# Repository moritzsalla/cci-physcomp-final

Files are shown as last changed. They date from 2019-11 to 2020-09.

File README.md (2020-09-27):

# Theremin

Experiemental instrument that uses light as an interface to output tones & melodies. It can be played by a single player or as a dialog between two.

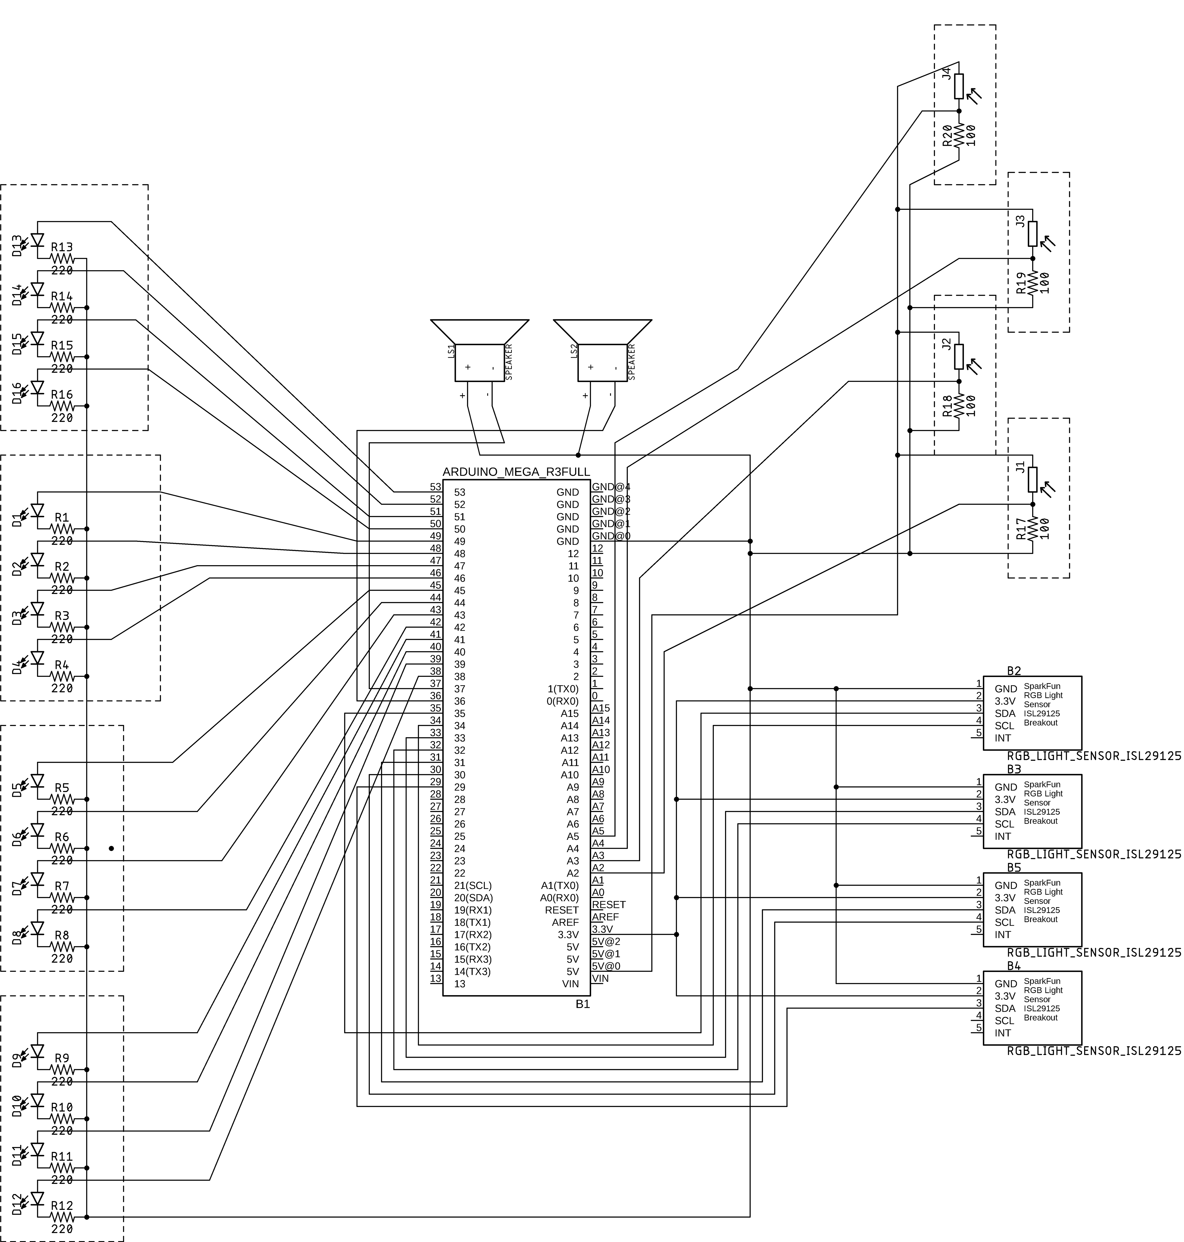
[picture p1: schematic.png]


## Dependencies

1. SoftWire
2. ISL29125 SoftWire

## Folder Structure

```
.
├── README.md
├── code
│   ├── libs
│   │   ├── ISL29125_softwire
│   │   │   ├── LICENSE.md
│   │   │   ├── README.md
│   │   │   ├── examples
│   │   │   │   └── ISL29125Basics
│   │   │   │       └── ISL29125Basics.ino
│   │   │   ├── library.properties
│   │   │   └── src
│   │   │       ├── ISL29125_SoftWire.cpp
│   │   │       └── ISL29125_SoftWire.h
│   │   └── softwire
│   │       ├── README.TXT
│   │       ├── SoftwareWire.cpp
│   │       ├── SoftwareWire.h
│   │       ├── examples
│   │       │   ├── Small_example
│   │       │   │   └── Small_example.ino
│   │       │   ├── StressTest_Master
│   │       │   │   └── StressTest_Master.ino
│   │       │   └── StressTest_Slave
│   │       │       └── StressTest_Slave.ino
│   │       ├── keywords.txt
│   │       └── library.properties
│   └── theremin
│       ├── calibration.ino
│       ├── header.h
│       ├── light.ino
│       ├── read.ino
│       ├── theremin.ino
│       └── tone.ino
├── journal
│   ├── log-01
│   │   ├── README.md
│   │   ├── render-1.jpg
│   │   ├── render-2.jpg
│   │   ├── scan-001.png
│   │   ├── scan-002.png
│   │   ├── scan-003.png
│   │   ├── scan-004.png
│   │   ├── scan-005.png
│   │   ├── scan-006.png
│   │   ├── scan-007.png
│   │   ├── scan-008.png
│   │   ├── scan-009.png
│   │   ├── scan-010.png
│   │   ├── scan-011.png
│   │   ├── scan-012.png
│   │   └── scan-013.png
│   ├── log-02
│   │   ├── README.md
│   │   ├── image-001.jpeg
│   │   ├── image-002.jpeg
│   │   ├── image-003.jpeg
│   │   ├── image-004.jpeg
│   │   ├── image-005.jpeg
│   │   ├── image-006.jpeg
│   │   ├── image-007.jpeg
│   │   └── image-008.jpeg
│   ├── log-03
│   │   ├── README.md
│   │   ├── image-1.jpg
│   │   ├── image-2.jpg
│   │   ├── image-3.jpg
│   │   ├── image-4.jpg
│   │   ├── image-5.jpeg
│   │   ├── schematic.jpg
│   │   ├── screenshot-1.png
│   │   ├── screenshot-2.png
│   │   └── screenshot-3.png
│   ├── log-04
│   │   ├── Bildschirmfoto\ 2019-11-26\ um\ 15.17.12.png
│   │   ├── Bildschirmfoto\ 2019-12-06\ um\ 18.15.19.png
│   │   ├── Bildschirmfoto\ 2019-12-06\ um\ 18.15.39.png
│   │   ├── README.md
│   │   ├── image-1.jpg
│   │   ├── image-2.jpg
│   │   ├── image-3.jpg
│   │   ├── screenshot-0.png
│   │   ├── screenshot-1.png
│   │   └── screenshot-2.png
│   ├── log-05
│   │   ├── README.md
│   │   ├── image-01.jpeg
│   │   ├── image-02.jpeg
│   │   ├── image-03.jpeg
│   │   ├── image-04.jpeg
│   │   ├── image-05.jpeg
│   │   ├── image-06.jpeg
│   │   ├── image-07.jpeg
│   │   ├── image-08.jpeg
│   │   ├── image-09.jpeg
│   │   ├── image-10.jpeg
│   │   ├── image-11.jpeg
│   │   └── image-12.jpeg
│   ├── log-06
│   │   ├── README.md
│   │   └── render.jpg
│   ├── log-07
│   │   ├── README.md
│   │   └── image-1.png
│   ├── log-08
│   │   ├── README.md
│   │   ├── image-1.jpeg
│   │   ├── image-2.jpeg
│   │   ├── image-3.jpeg
│   │   ├── image-4.jpeg
│   │   └── image.png
│   ├── log-09
│   │   ├── README.md
│   │   └── schematic.png
│   └── log-10
│       ├── README.md
│       ├── image-1.jpg
│       └── schematic.png
├── presentations
│   ├── final.pdf
│   ├── proposal.pdf
│   └── theremin-1.mp4
├── renderings
│   ├── render-1.jpg
│   ├── render-2.jpg
│   ├── render-3.jpg
│   └── render.gif
└── schematic.png
```

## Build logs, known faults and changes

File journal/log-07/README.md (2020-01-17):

# Log 7

### Using millisec instead of delay

Fading my led torches is all fun and games until you want to do something in parallel. The delay function will block your loop. The solution to this is to use milliseconds.

### Fading the LED torches

Another solution had to be found, and hence I settled on a function that would allow me to use time and a sine wave to fade the LEDs. Not only does this solve the timing problem, the sine wave fade is much better looking than the linear for loop fade.

https://youtu.be/ubPF3j_LVvM

https://youtu.be/BusSimIUbJU

```c++
int LEDval, LEDval2;

void light () {
      LEDval = 128 + 128 * sin(2 * PI / frequency * (millis()));
      analogWrite(ledA1, LEDval);
}
```

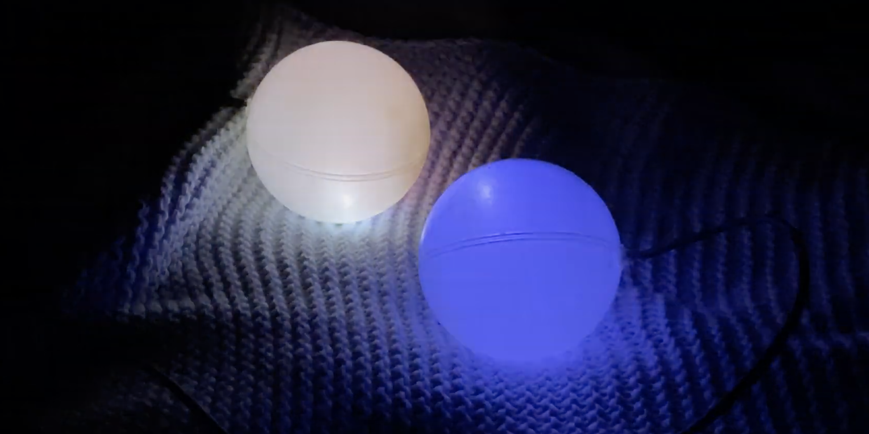
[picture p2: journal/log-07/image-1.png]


In order to have the two run asynchonously, one has to run on an offset. This can be easily achieved by using a sine curve on one, and a cosine curve on another value.

```c++
LEDval = 128 + 128 * sin(2 * PI / frequency * (millis()));

LEDval2 = 128 + 128 * cos(2 * PI / frequency * (millis()));
```

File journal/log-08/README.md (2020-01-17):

# Log 8

#### Complex tones

This by far became the most challengin aspect of my porject. By standard, the tone function is limited to a single output. Also, the square wave that the Arduino produces sounds harsh on the ears. Creating something that would be more complex than a simple one to one reading of the sensor values wasn't going to be easy.

Tryout using random() to create tones—not quite what I am going for:

https://youtu.be/zJvzaO4Gy4U

The low accuracy of the RGB sensors returns this magnificent staggered wave. It's much easier on the ear than a continuous tone, and sounds remarkeably interesting.

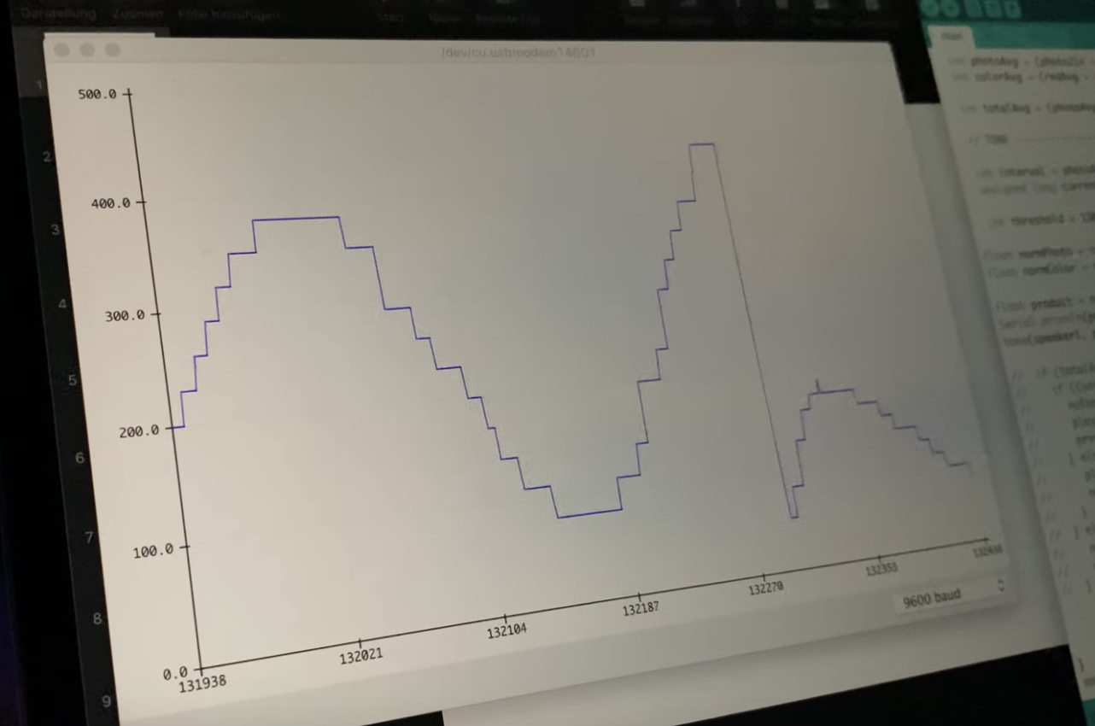
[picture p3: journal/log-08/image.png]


https://youtu.be/a39MprkitpA

When the frequency drops below a certain value, the loudspeakers will start to play random pitches until the value of zero. Don't quite understand why this is happening. I have mapped the value so that these frequencies are omitted.

#### Finding a better material for the enclosure

Went to another art supply shop. Silicone/latex seems the way to go. He only had the brown one though, albeit selling pigments. Pigments wont work because they likely make the material opaque. I need it semi translucent. Need to order this stuff on the internet. I ended up using a mixture of latex thickener and white color to create the desired effect.

The LED torches were a challenge to coat. I initially wanted to create a surface that would monotonously disperse light just like the Playstation controllers. I quickly discovered that the tactility of latex adds a lot to my project. The plastic baubles were suddenly satisfying to grip, didn't slip and looked more approachable. Latex became a signifier, I guess?

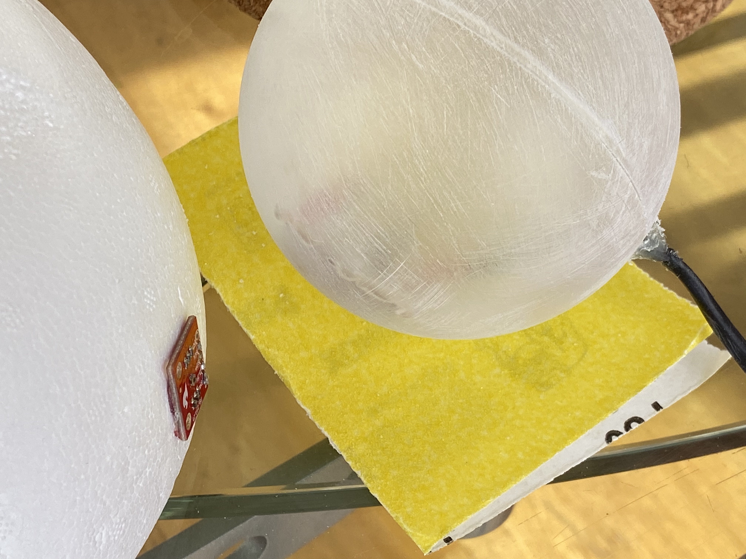
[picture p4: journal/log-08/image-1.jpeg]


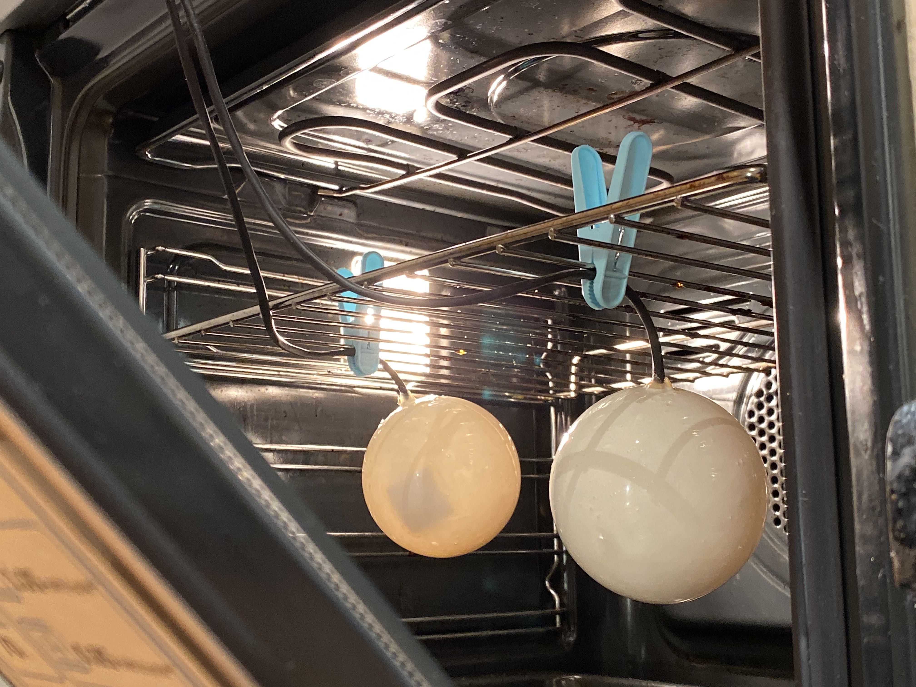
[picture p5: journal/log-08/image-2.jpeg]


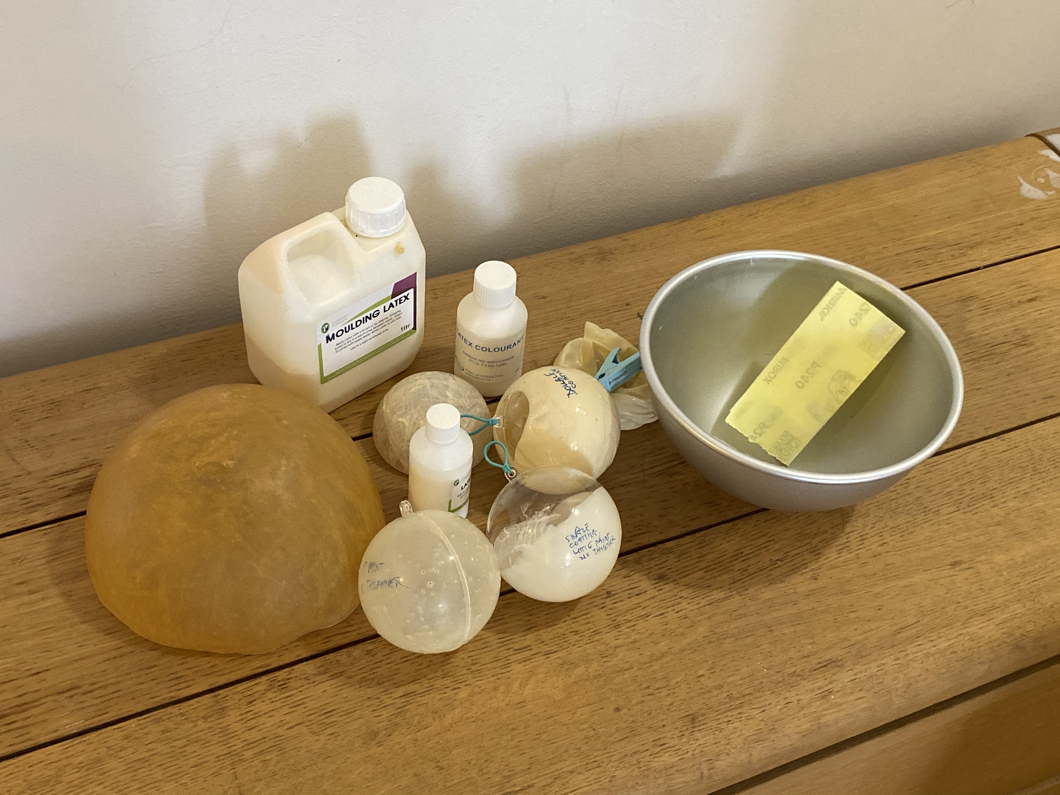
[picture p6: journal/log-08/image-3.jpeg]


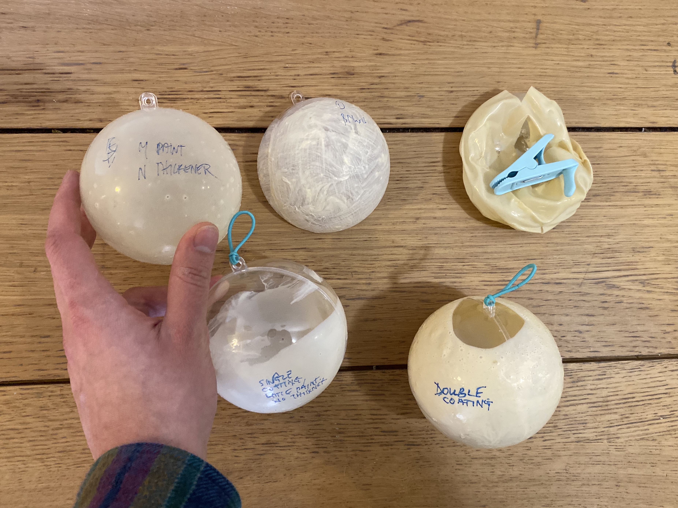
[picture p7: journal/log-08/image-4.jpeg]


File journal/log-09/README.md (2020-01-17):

# Log 9

## Redoing the circuit diagram

I figured that the fritzing diagram I made was not actually a schematic. Since I had to redo this, I took the challenge to make it in Eagle, the program with one of the scariest interfaces I have ever seen (or lack thereof). Getting all of my sensors onto a single diagram proved to be quite difficult, as I quickly ran out of space for my nets.

Schematic

## Distance sensor

In order to create a threshold in which the instrument turns on, I used the photoresistor readings. If the value goes above a cetrain amount, a tone will be played, whereas it will be stopped should the value drop. I have basically created a distance sensor from photoresistors.

## Enclosure and sensors work together

Things are coming together now. I was slightly concerned the color sensors wouldn't work properly with the reddish latex enclosure but it works perfectly. Interestingly I can use shadow instead of light, and it will have the inverted effect on my sensors. This is an alternative way of interacting with the instrument, and an ally I could further explore.

https://youtu.be/4mwHbQ01Eho

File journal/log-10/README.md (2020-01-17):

# Log 10

## Naming my instrument

My aunt hinted that what I had created already existed, and was called a **Theremin**. Albeit this being an instrument that works with a single input and a single output, the core concept seemed to be similar to mine: to create music without direct physcial interaction. Therefor, I chose to adapt the name Theremin. Here is a short description of the original instrument, found on Wikipedia:

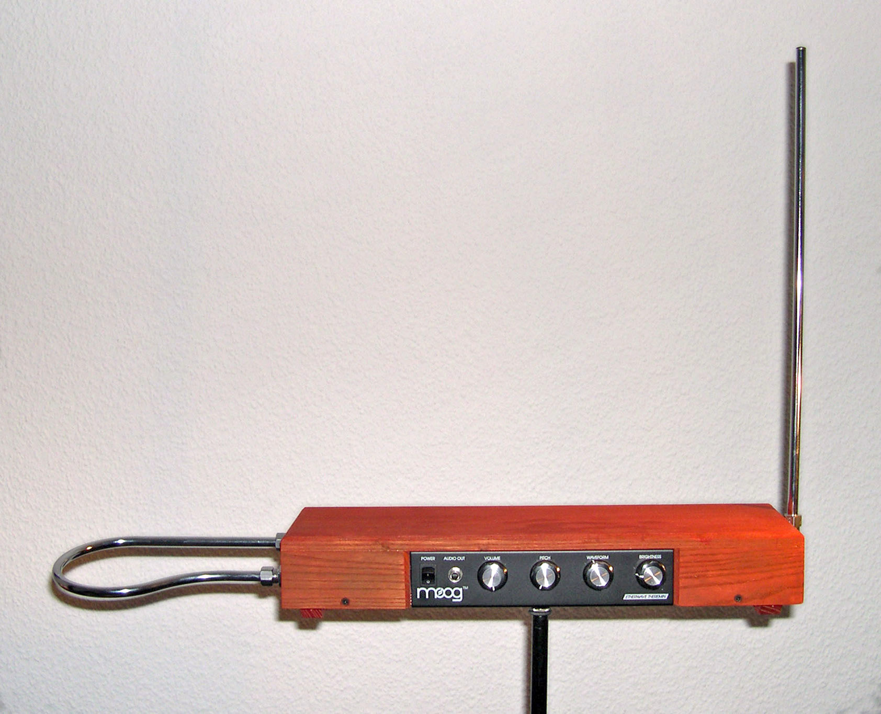
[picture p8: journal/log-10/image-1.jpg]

_Theremin. Image taken from wikipedia._

**_The theremin is an electronic musical instrument controlled without physical contact by the thereminist. It is named after its inventor, Léon Theremin, who patented the device in 1928._**

## Adding a calibration routine

When working with light, calibration is crucial. Light changes constantly—even dark rooms differ in ambient lighting. I could'nt propperly showcase my project in CCi as the building is covered in glass. However, my feedback was to add a calibration routine to my script, in order for Theremin to automatically adjust to ambient light levels. This code represents a single calibration routine, taken from an Arduino tutorial:

```c++
void setup() {
  pinMode(13, OUTPUT);
  digitalWrite(13, HIGH);

  while (millis() < 5000) {
    sensorValue = analogRead(sensorPin);

    if (sensorValue > sensorMax) {
      sensorMax = sensorValue;
    }

    if (sensorValue < sensorMin) {
      sensorMin = sensorValue;
    }
  }
  digitalWrite(13, LOW);
}

void loop() {
  sensorValue = analogRead(sensorPin);

  sensorValue = map(sensorValue, sensorMin, sensorMax, 0, 255);

  sensorValue = constrain(sensorValue, 0, 255);

  analogWrite(ledPin, sensorValue);
}
```

I have done this for the photoresistors. The color sensors actually don't need calibration, because there tends to be very little color in dark rooms. The readings seem very consistent. Perhaps the library that comes with the RGB color sensors includes its own calibration routine. I did look through the code. Can't remember having seen one though. Furthermore, the threshold that determines when the instrument turns on doesn't have to be calibrated either, as the calibrated photoresistor input will yield the same results.

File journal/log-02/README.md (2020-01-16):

# Log 2

I've started ordering components. Four ambient light sensors to be specific. Initially, I wanted to go for more than four sensors of each sort but since spending such an amount of money didn't increase the accuracy much, I cut it down to four.

In the meantime, I started soldering little breakout boards for the photoresistors. Not only will this reduce the cable salad on my central perfboard by compartmentalizing the components, but it'll also be more reliable.

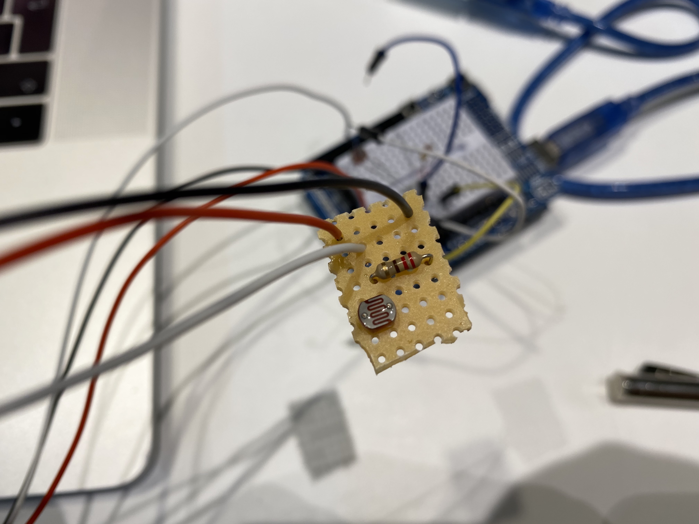
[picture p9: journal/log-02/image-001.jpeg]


Taping the cables together close to the breakout board will helpfully spread force to all of the cables should they be accidentally pulled. This'll hopefully reduce the chance of a cable getting lose. Since I'm dealing with so many sensors at once, it'll be a nightmare to spot errors if things go wrong. Better be safe then sorry.



For now I am using this styrophome ball to prototype. I poke holes into the ball in order to bring all the technology together on the inside. The sensors will be stuck, not floating around like in the picture.

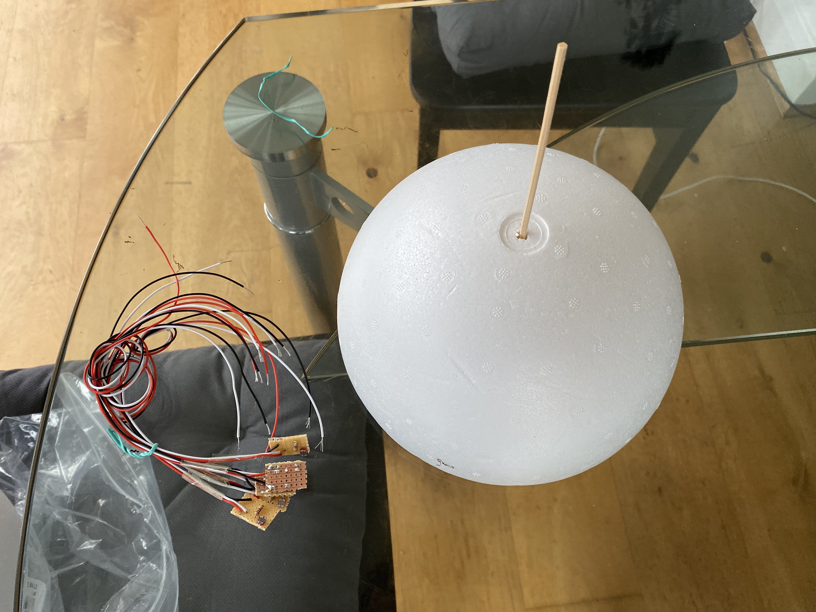
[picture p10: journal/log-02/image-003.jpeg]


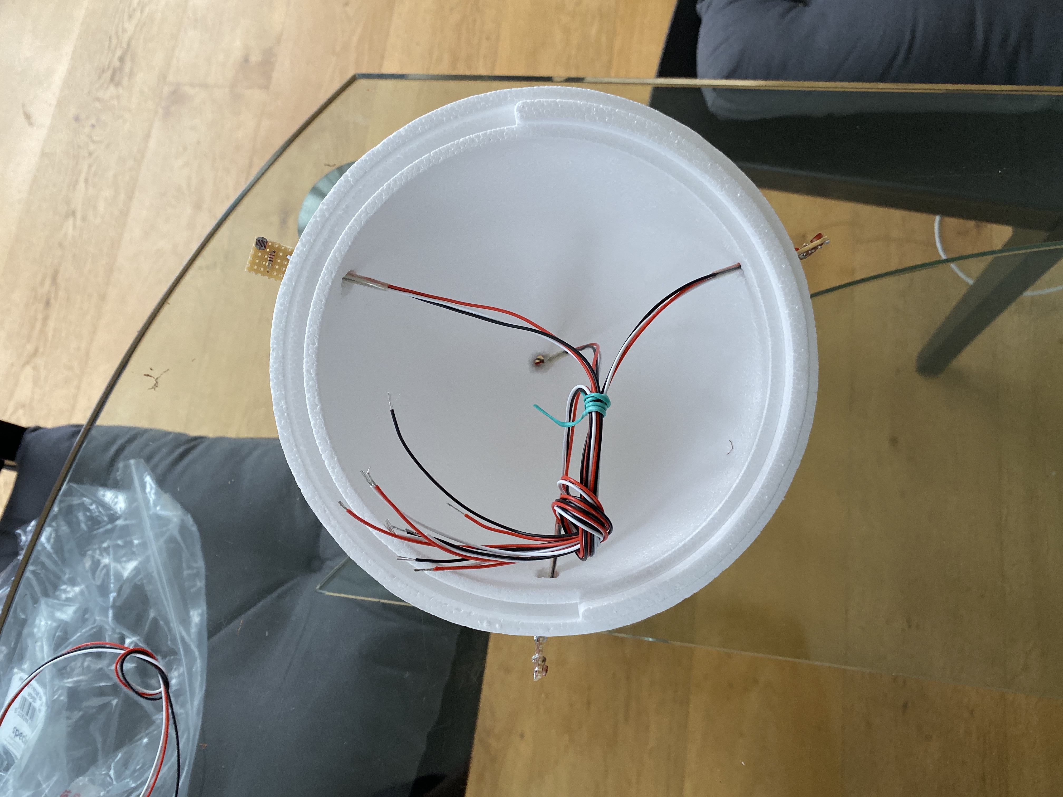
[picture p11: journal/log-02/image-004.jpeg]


The ambient light sensors (ISL29125 RGB Light Sensor [SEN-12829]) have arrived and I am testing them out. They work! The output is in HEX color values—I hope Arduino provides an easy way to convert these to floating-point. One of these breakout boards requires two analog ins. Here is the official documentation: https://learn.sparkfun.com/tutorials/isl29125-rgb-light-sensor-hookup-guide

**Two important points to remember about these sensors:**<br>

1. The chip is not 5V tolerant and will be damaged if you apply 5V to power or any of the inputs
2. Connect the 3.3V and GND on the Arduino to the 3.3V pin on the breakout board. Connect SDA on the breakout to A4 on the Uno, SCL to A5 on the Uno.

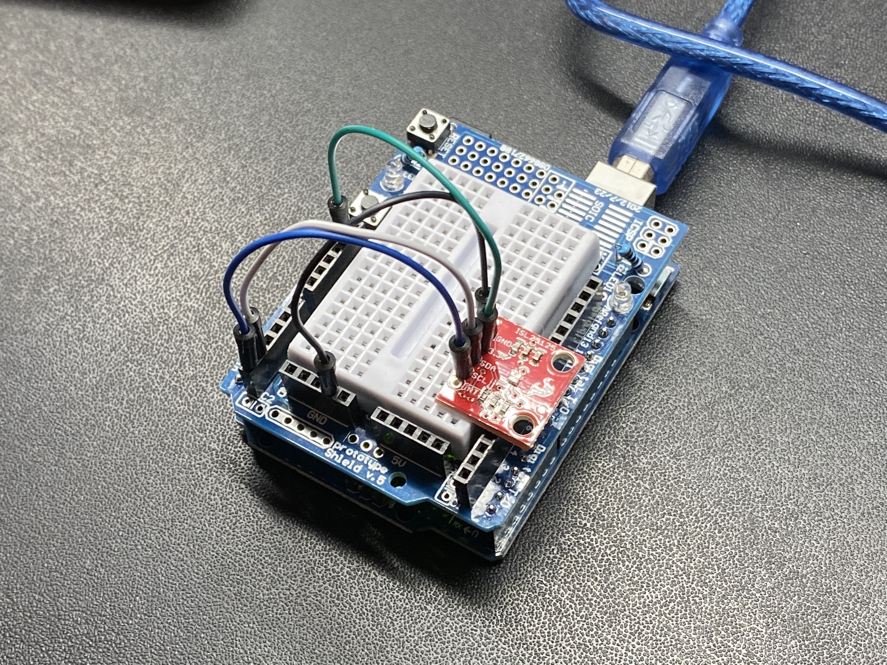
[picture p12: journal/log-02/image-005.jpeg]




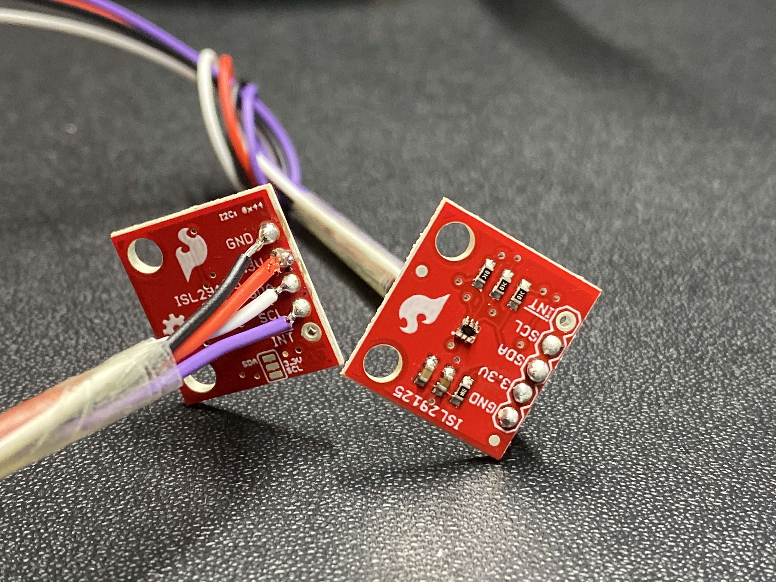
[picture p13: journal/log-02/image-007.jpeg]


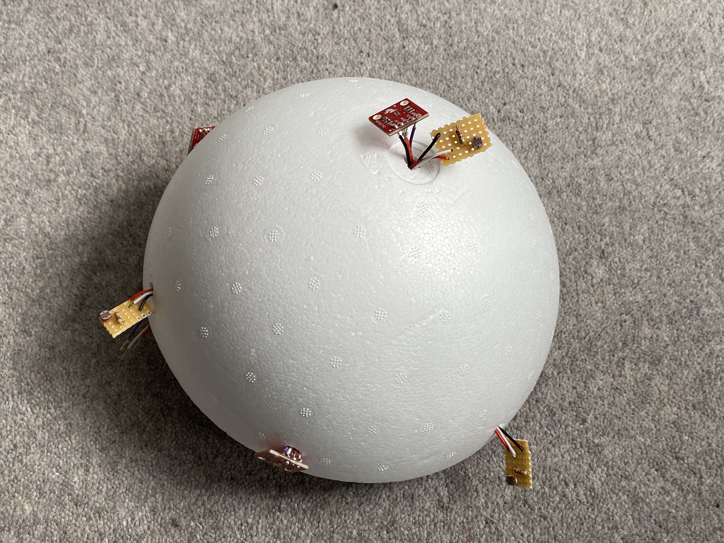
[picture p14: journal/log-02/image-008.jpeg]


Bought my own Board, a Sunfounder Mega (SUNFOUNDER Mega 2560 R3). It accommodates 16 analog ins, whereas the leonardo only has 6. Since I need 12 and multiplexing is not an option, this is the optimal board. I was thinking of using two Arduinos but setting up a serial connection between them and packing all of that wire jungle into relatively compact space convinced me to just spend the money in order to greatly simplify life.

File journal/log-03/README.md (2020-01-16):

# Week 3

I have received my new board!

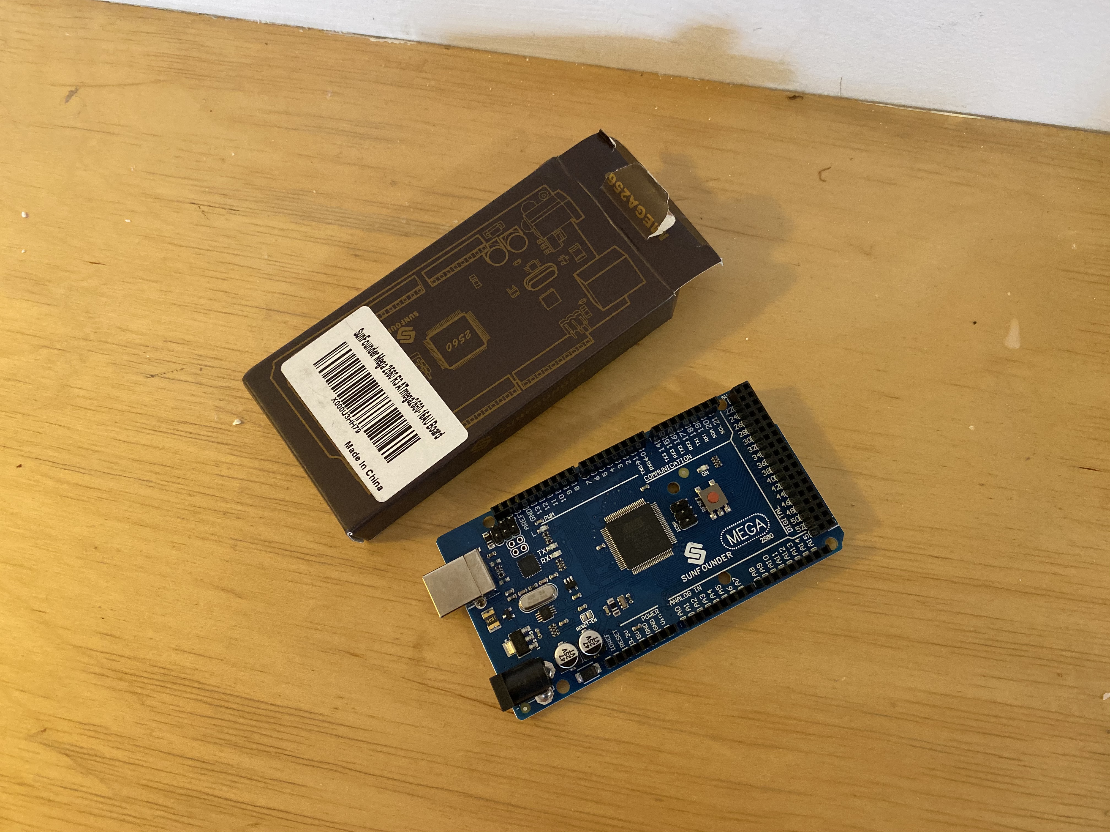
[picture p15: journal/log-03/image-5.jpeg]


### Dealing with color values

Since I now have my hands on a suitable board and my color sensors, I can fetch some readings. The ISL29125s require an external library which is downloadeable from the makers website. Also, they are read through the I2C ports, which I have never used before. Luckily it is easy to read decimal and heximal values through Arduino. The latter is not of importance for me. The difference can be seen by including DEC or HEX as a second argument in the Serial.println() function.

- DEC = decimal
- HEX = hex color values

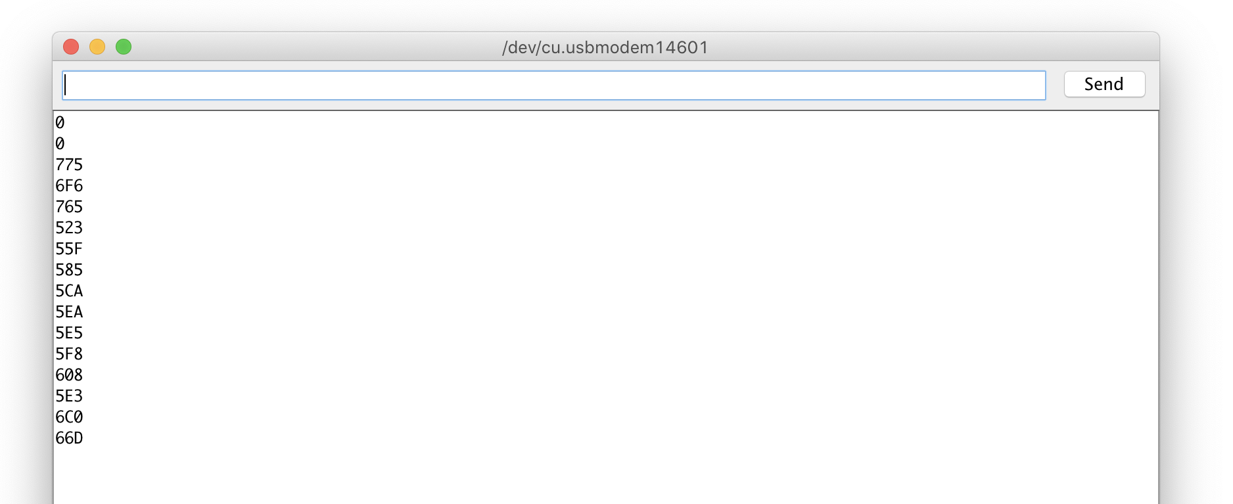
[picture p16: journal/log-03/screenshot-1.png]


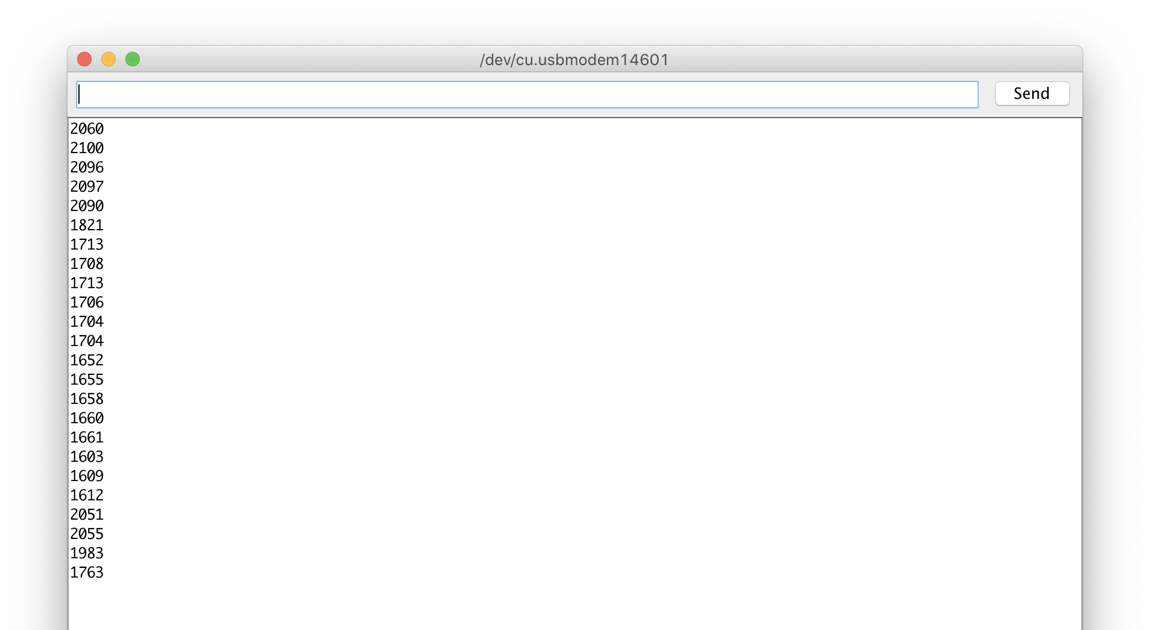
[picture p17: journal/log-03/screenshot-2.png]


### I2C Ports

The Uno uses the A4 & A5 for SDA and SLA. It took me quite some time to figure out which ports the Mega uses, when finally I realized it has dedicated pins. How many Devices can you Connect to the I2C Bus? Connecting all four RGB sensors yields incorrect results. This is a problem I will have to address later. Here are some good resources I found on I2C connections:

- https://www.bluedot.space/tutorials/how-many-devices-can-you-connect-on-i2c-bus/
- http://www.goodliffe.org.uk/arduino/i2c_devices.php
- https://www.bluedot.space/tutorials/how-many-devices-can-you-connect-on-i2c-bus/
- https://maker.pro/arduino/projects/arduino-speaker
- https://forum.arduino.cc/index.php?topic=77447.0
- https://www.programmingelectronics.com/an-easy-way-to-make-noise-with-arduino-using-tone/

### Photoresistors

Getting a single reading was unreasonably teadious. I quickly realized all sensors had to be in parallel autonomous, or they would multiply themselves. Hence, I will solder little breakout boards that individually connect to the board and have independent power supplies. A good debugging tool is the multimeter, as I can test if there is current on the breakout board. Even at peak brightness, the Arduino seems to receives less current than it outputs, when run through a photoresistor.

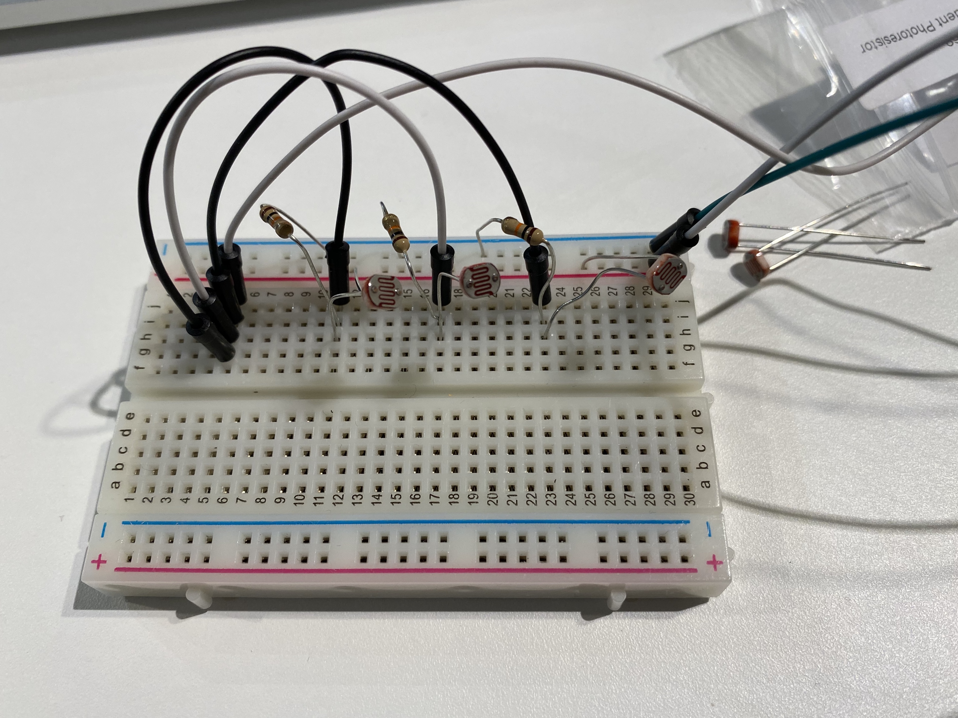
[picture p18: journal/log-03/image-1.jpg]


```c++
int brightness = 0;

void setup() {
  pinMode(A0, INPUT);
  Serial.begin(9600);
}

void loop() {
  brightness = analogRead(A0);
  brightness = map(brightness, 599, 880, 0, 255);
  Serial.println(brightness);
  delay(500);
}
```

### Power and ground

Before I realized that both sensor types require different power supplies because 5V will break one of kind… Painstaikingly had to solder it a third time after the perfboard chipped on me (the usual). The solder doesn't bond well to the copper at all.

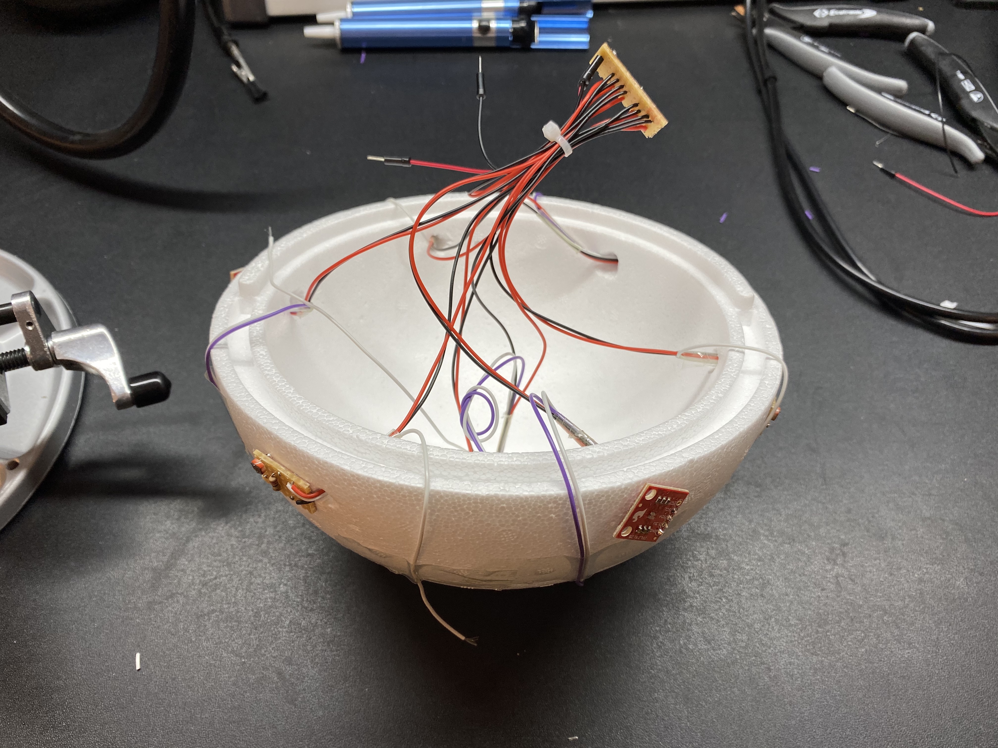
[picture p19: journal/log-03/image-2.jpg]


Just had David Crow pop up behind me and explain my project to a group of visitors. Practice makes perfect, I guess. Hope I don't spot another mistake now. This compartementalizes power and ground to make things easier. Since I only have very limited power pins on the arduino, it's necessary to bring everything together anyways.

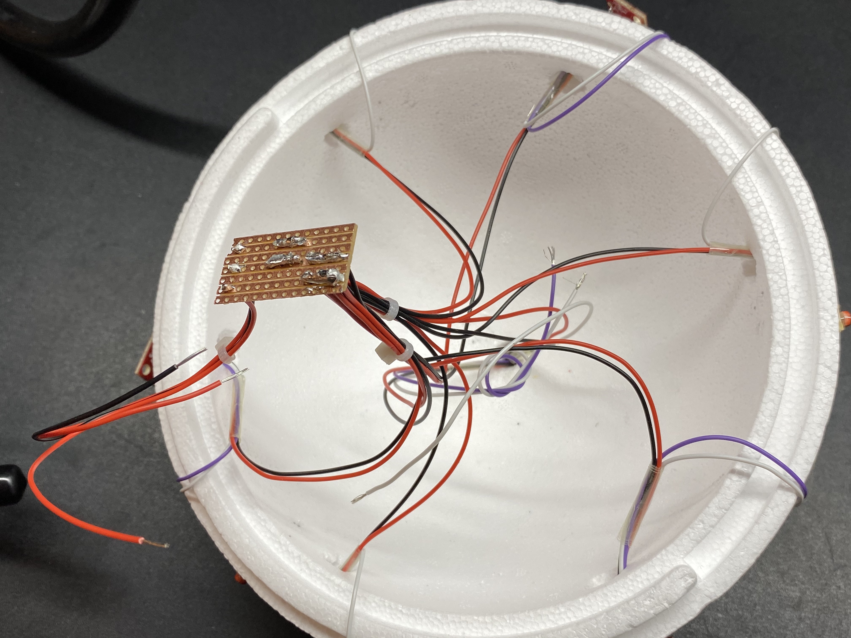
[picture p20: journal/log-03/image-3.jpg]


I keep ground in the center lane. The 3.5V is on the left, the 5V on the right lane next to center.

### Testing the circuit

All the sensors seem to be getting their electricity. Tested both lanes with 3.5V from the Arduino. I get 3.322V on both of them, is this their combined resistance? Checked the current straight from the Aruduino which is 3.341V. Where is the 0.178V being lost?

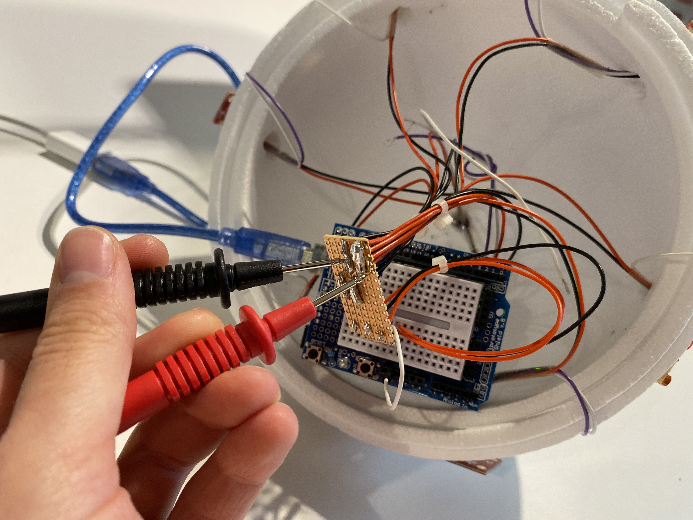
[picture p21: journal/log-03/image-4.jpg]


### Bi-Directional Logic Level Converter

Even though I can power the sensors with 3.5V, it appears like I need a logic level converter between the SDA/SCL and serial pins on the Arduino.

> "Connect SDA on the breakout to A4 on the Uno, SCL to A5 on the Uno. If you're using the Uno or any 5V Arduino, you'll need a logic level converter between SDA/SCL on the breakout and A4/A5 on the Uno."

I have ordered one "SparkFun Logic Level Converter - Bi-Directional" with the hopes of being able to connect all my sensors to it at once. Here is it's hookup guide: https://learn.sparkfun.com/tutorials/bi-directional-logic-level-converter-hookup-guide. In the end I realized that a logic level converter was not necessary, as the readings from the RGB sensors don't have to be perfectly accurate to create an interesting tone.

### Schematic

I later figured this wasn't a propper schematic, and remade it in eagle. See log 9.

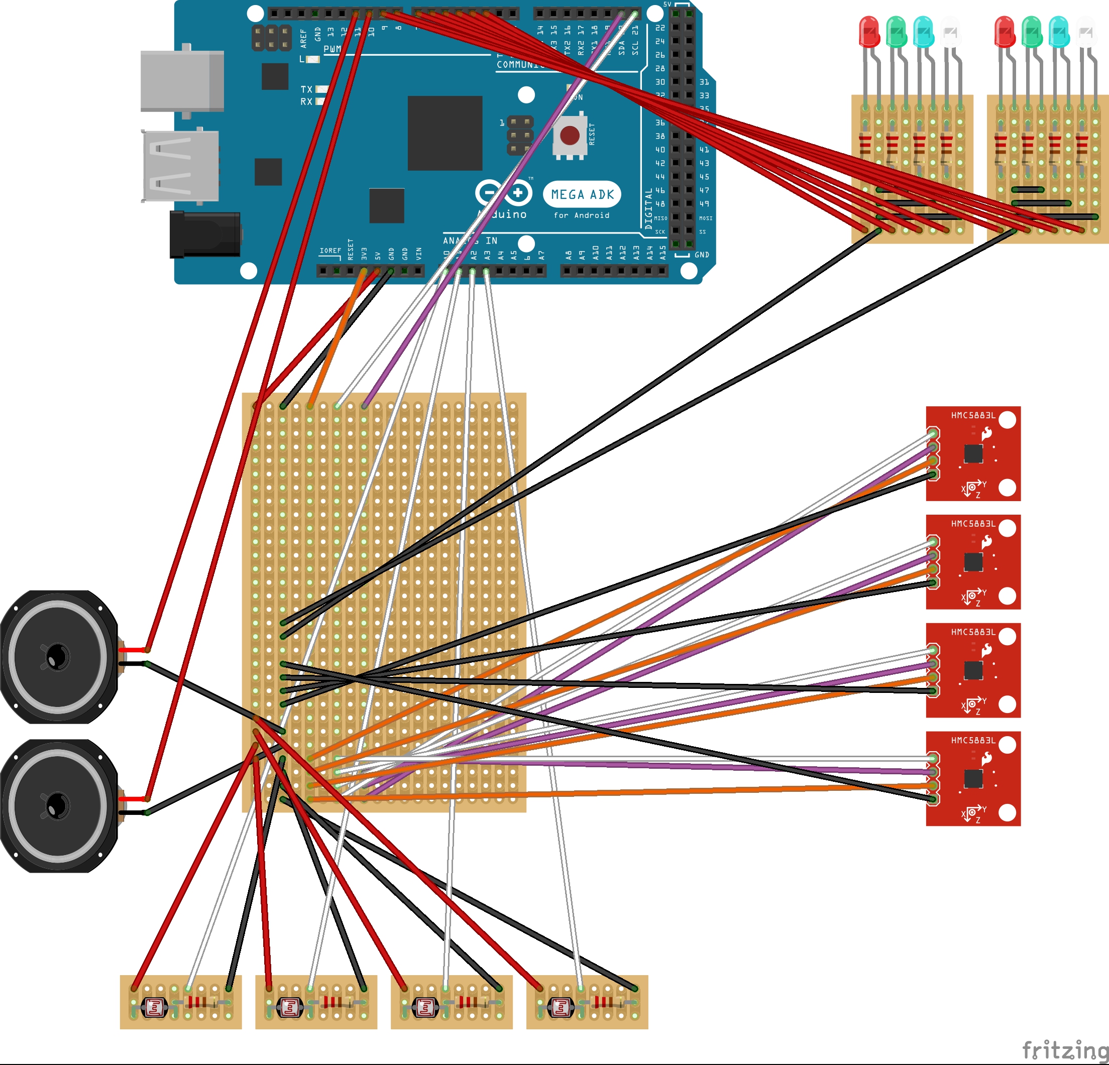
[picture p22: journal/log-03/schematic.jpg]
Schematic


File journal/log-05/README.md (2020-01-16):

# Log 5

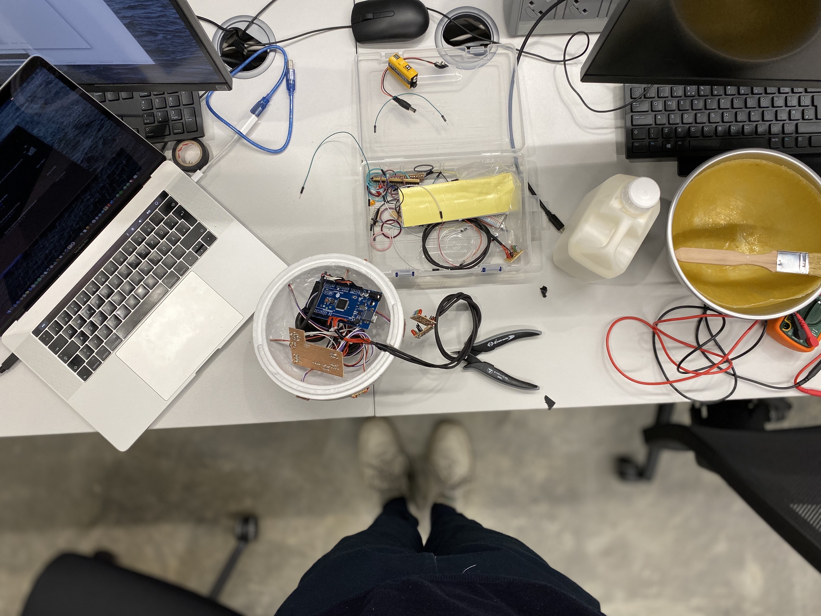
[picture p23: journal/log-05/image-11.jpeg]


### Loudspeakers

Time for the first outputs! The loudspeakers have arrived and are working like a charm. I have found an open source tone library that simplifies the creation of melodies. Since they came with a wobbly cable and some sort of female plug I stripped them and resoldered the connection. Using hot glue, I will glue them to the inside of the dome, projecting downwards. This will disperse the sound more evenly compared to just chucking them in loosely with all the other components (the underground surface disperses the sound waves). Also, this saves space.

https://youtu.be/ip19ULygueg

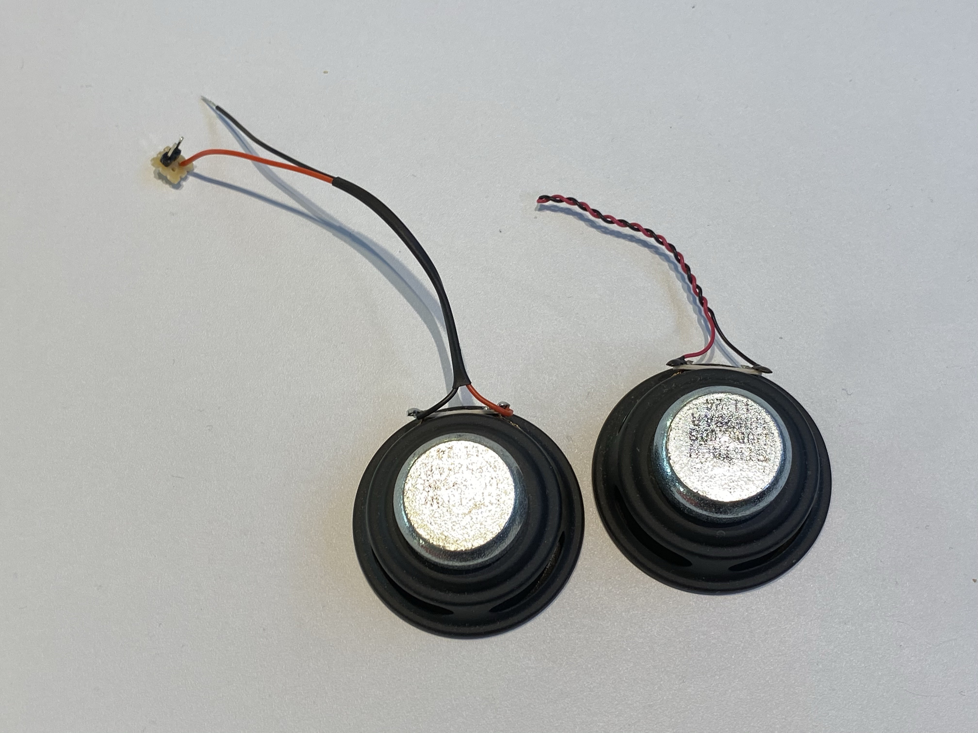
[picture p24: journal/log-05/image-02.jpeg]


### LEDs

LED strips, soldered in parallel. These can be individually accessed through the megs PWM pins.

https://youtu.be/iWTKAIUq5a8

https://youtu.be/PpH0G7DInRk

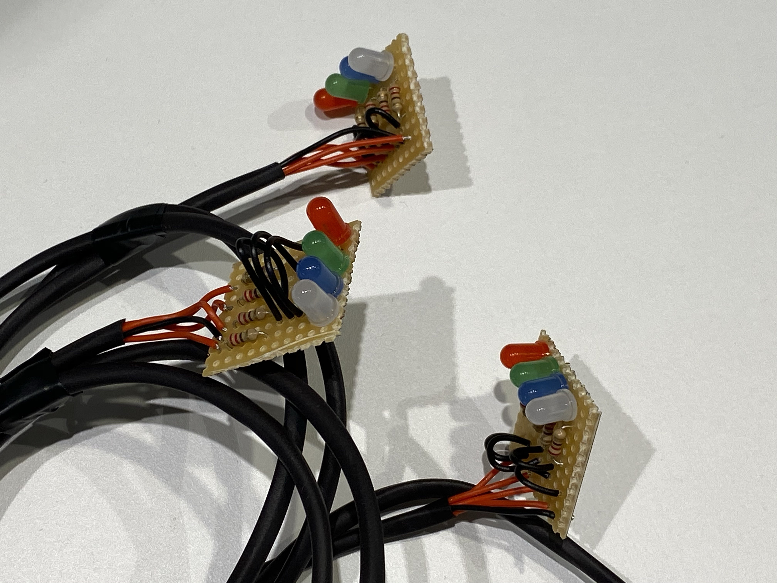
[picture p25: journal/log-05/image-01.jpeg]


### Casing

I've bought silicone to cast a membrane that will act as my casing. It should be semi-translucent and ideally colorless. It's purpose is to hide the wiring, hence making it more approachable for the audience. I want to create a mistery around my piece, and give it a uncanny flesh like texture. The LED torches will be cast from the same material. PS3 had these neat accessory controllers (Sony PlayStation 4 Move controller set), this would be ideal:



Some more inspiration I found in a shop in china town:

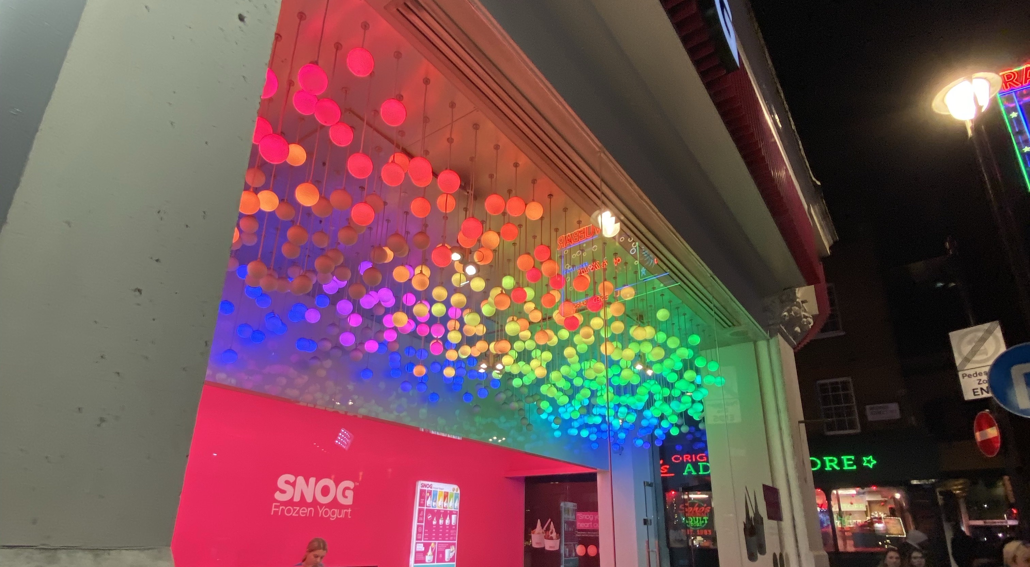
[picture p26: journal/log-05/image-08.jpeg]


Getting my hands dirty. Working with latex is not as easy as it looks. It dries rather slowly. Its difficult to create the right thickness. Also, it will take on any bristle strokes from the brush you are using to coat the mold. Furthermore, it changes color and becomes brown. I haven't figured why this is the case, either because it reacts to light or my tote bag.

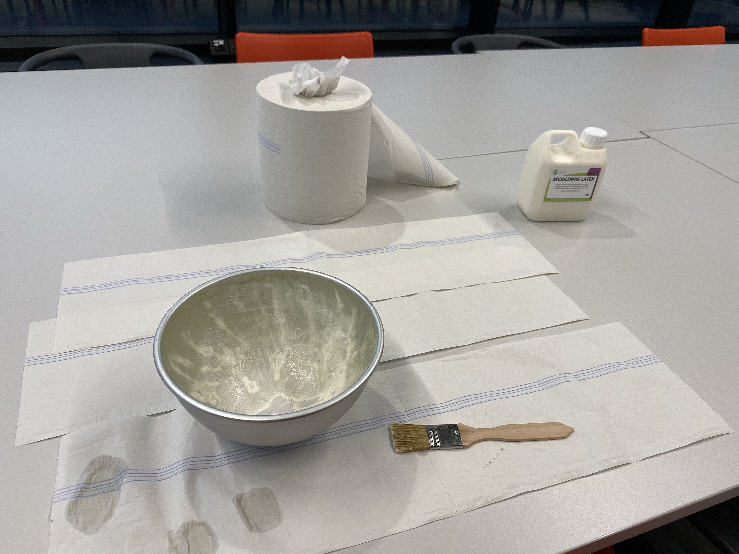
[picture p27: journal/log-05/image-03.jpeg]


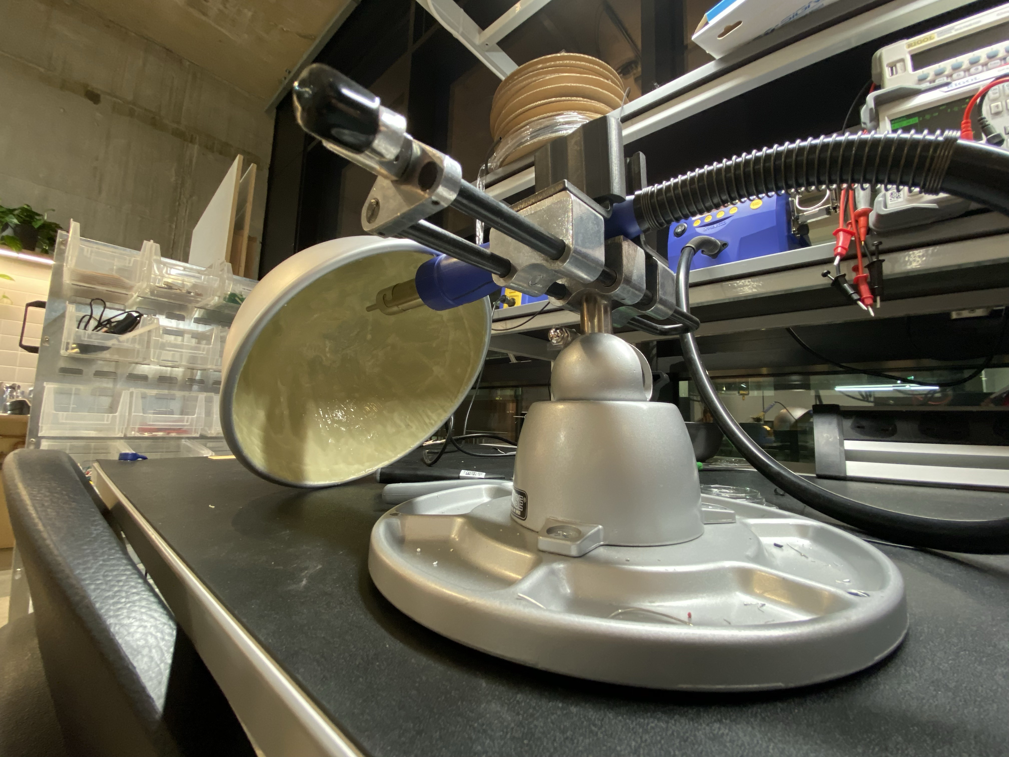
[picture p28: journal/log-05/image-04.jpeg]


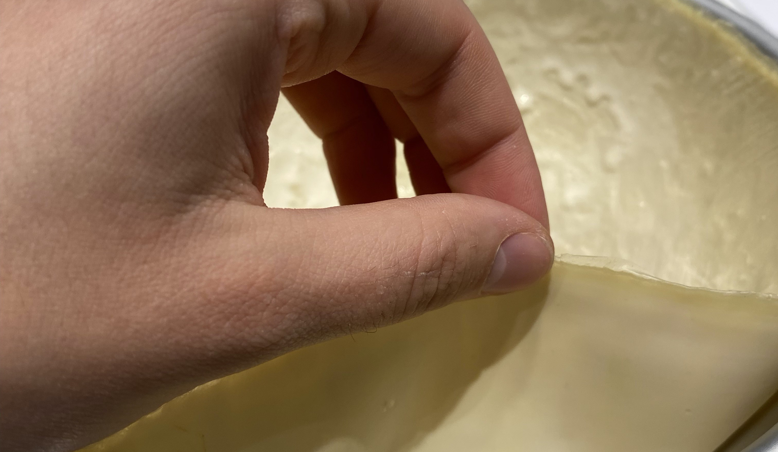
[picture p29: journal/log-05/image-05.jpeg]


Half an hour into drying time the silicone appeared competely opaque with little color tint. A day after the casting the silicone turned semitransparent, albeit having taken on a very distinct color. This will skew sensor readings. The texture is perfect though. I'll need to find a similar, colorless material.

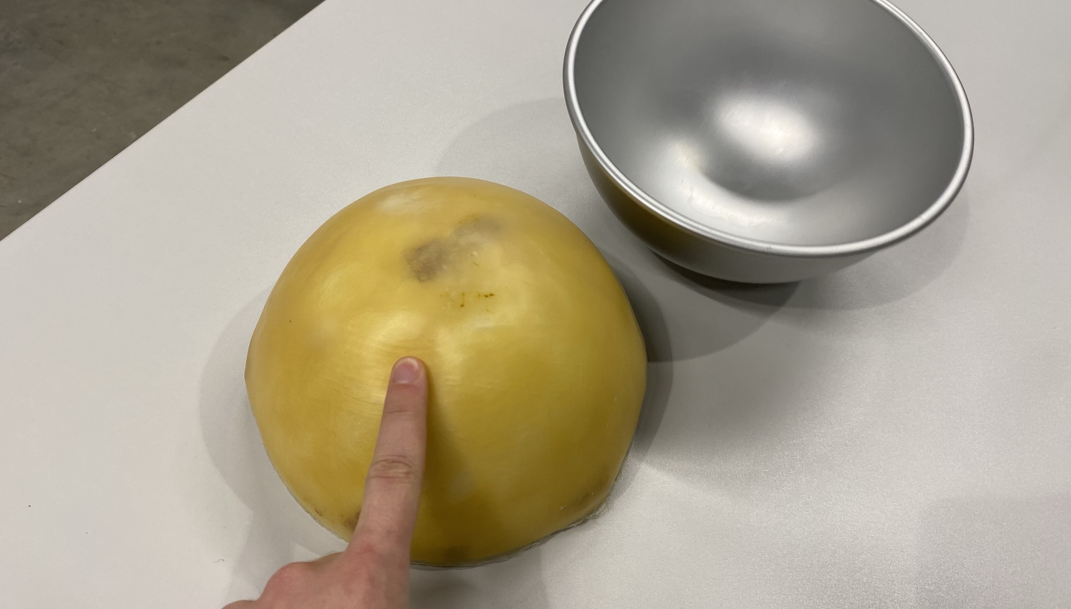
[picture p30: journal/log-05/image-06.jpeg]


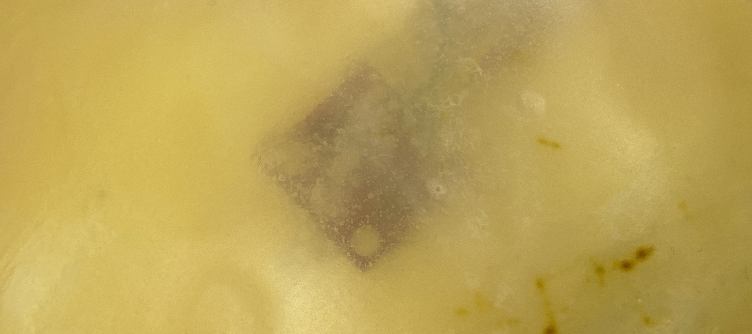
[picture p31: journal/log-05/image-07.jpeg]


### Final Interior

The interior is finalized. All components fit into the inside and are functional. A battery will power the arduino. I have cut an opening into the dome for the cables to exit. These will conenct the LED torches to the main perfboard. The loudspeakers are glued to the inside of the dome using hot glue and are projecting downwards. This reduces the chance of accidentally shortcuiruiting the board, as metal parts can touch.



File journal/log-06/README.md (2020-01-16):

# Log 6

I've made some renderings to help me visualize how the interaction might take place. Rendering with ray tracing actually gives a good impression on what will work, and what won't in terms of light, color and brightness.



### Multiple I2C slaves: Solution

1. ISL29125s use the same address (1000100), which is hardwired. It therefore cannot be changed. christosku's library uses the Adafruit TCS34725 Color Sensors lib as a work around. It enables you to use different pins.

2. Another option is to use PCF8575 i2c expander ICs. The data will cannot be read synchronously, though. Instead, the Arduino cycles through the slaves.  
   https://www.ebay.com/itm/PCF8575-IIC-I2C-I-O-Extension-Shield-Module-16-bit-SMBus-I-O-ports-For-Arduino-/351954909169

3. Another option is to use a 74HC4067 multiplexer.

What happens when I connect all of them to a single bus? The sensors addresses cannot be changed but perhaps this is not an issue. If the mashup of combined signals arent distorted or overamplified, it will suffice. I don't need to locate which sensor is returning which value.

- https://github.com/christosku/ISL29125_SoftWire
- https://github.com/Fire7/SoftwareWire

I am so happy I found this. These two libraries allow for software emulation of I2C connectivity. I am using my spare analog pins as inputs. This'll allow me to finally use all 4 ambient light senors at once without the pain of using a multiplexer.

#### Pulse Width Modulation (PWM)

I need pulse width modulation to incrementally control the led torches. Still thinking how the light might actually be user controlleable, or if it should be at all. This isn't necessary but might be an interesting addition. Perhaps for a future iteration.

I have created a function fades an led between certain values. When at max, it fades back to min. Endless loop. Starting point for more complex functions.

https://youtu.be/EKUP-7Uccfg

```c++
void torch_single_fade (int i, int t) {
  for (int fadeValue = 0 ; fadeValue <= 255; fadeValue += 1) {
    analogWrite(i, fadeValue);
    delay(t);

    if (fadeValue == 255) {
      for (int fadeValue = 255 ; fadeValue >= 0; fadeValue -= 1) {
        analogWrite(i, fadeValue);
        delay(t);
      }
    }
  }
}
```

I continue to search for an interesting way to control my torches.

```c++
//led A
int led0 = 6;
int led2 = 8;
int led5 = 11;
int led6 = 12;

//led B
int led1 = 7;
int led3 = 9;
int led4 = 10;
int led7 = 13;

void led_fade (int led0, int led1, int t) {
  for (int fadeValue = 0 ; fadeValue <= 255; fadeValue++) {
    analogWrite(led0, fadeValue);
    analogWrite(led1, fadeValue);
    delay(t);
  }
  for (int fadeValue = 255 ; fadeValue >= 0; fadeValue--) {
    analogWrite(led0, fadeValue);
    analogWrite(led1, fadeValue);
    delay(t);
  }
}

void setup() {
}

void loop () {
  led_fade(ledA0, ledB0, random(2, 10));
  led_fade(ledA1, ledB1, random(2, 10));
  led_fade(ledA2, ledB2, random(2, 10));
  led_fade(ledA3, ledB3, random(2, 10));
}
```

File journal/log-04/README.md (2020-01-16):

# Log 4

## Physical Encasing

I have ordered a shperical cake form that will act as a mold for the outer skin of the semi–globe. I will cover the inside with a medium layer of silicone that I'll buy in the art shop. An outer skin will cover up the sensors, making the object more approachable, aesthetic and mysterious (by hiding i'ts functions). Further more, it will slightly even out light shown at the globe, in order to get better sensor readings.



I will create small globe torches in similar fashion. These are the molds I have ordered. Their internals will be simple--an array of LEDs connected to the arduino by distance. This'll allow programming light sequences, fading, and potential interaction.



## Resoldering

My compartmentalized approach made me run out of space. I've resoldered everything to a single, large perf board.



## Testing all sensors at once



```c++
float brightness = 0;

void setup() {
  Serial.begin(9600);
}

void loop() {
  // brightness = analogRead(A0);
  // brightness = map(brightness, 599, 880, 0, 255);

  Serial.print(analogRead(A0));
  Serial.print(",");
  Serial.print(analogRead(A1));
  Serial.print(",");
  Serial.print(analogRead(A2));
  Serial.print(",");
  Serial.print(analogRead(A3));
  Serial.println(",");
}
```

The mega can take a **max. stable baud rate of 115200**. This runs quicker but will choke the monitor/plotter when there is a mistake in the code. Using 5V will yield a much cleaner out. It's rather satisfying to watch this. One photoresistor seems to be disfunctional (red). I might have to resolder this one.



## To–Do

### Wiring

- 4th photoresistor isn't working. Find out why.
- Set ISLs to different addresses so that they can be individually read out.
- Find out why speaker_start() miraculously isn't in scope, altough other files are.
- Find out how to play 2 speakers at same time

### Encasing

- Find better, more transparent and less colored material than the silicone from art supply shop
- Wait for christmas bobles to arrive (torches)
- Pour torches using moldes

### Programming

- Get all sensors to work
- Troubleshoot minor problems

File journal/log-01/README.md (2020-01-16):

# Log 1

I’m interested in how atmosphere is created through sound and light. Possibly because I'm the son of an opera singer and have a fascination for set design and music tucked away somewhere. I'm inspired by how light and sound interplay in Annie Tådne's "[Boberg 1](https://tadne.se/performance/boberg-1/)" and Felix Faire's "[Contact](https://felixfaire.com/project/contact)" but feel the tabletop is quite an over-explored interface. Olafur Eliasson talks a lot about how work is created in the moment it is perceived by the viewer ("[Rainbow Assembly](https://olafureliasson.net/archive/artwork/WEK110117/rainbow-assembly)" is a good example of this).

This made me wonder if light can be used as an interface, for example, to create tone, compositions and perhaps even dialog. Possibly by measuring for example brightness, color, source (artificial or sun), and duration. I'm not yet sure if the light source is to be static and there for the viewer to manipulate, or if it is free for the audience to bring in their own dynamic light sources. The output is a synthesizer that produces an array of different tones, which makes it possible to compose a melody by playing with the light in certain ways. Does a complex synthesizer count as multiple outputs? If not, I'd have to rethink and possibly add a visualization (if this doesn't interfere with the light sensors) or vibration feedback. This idea could develop into a game, an instrument, a performance or perhaps even a sort of design for therapy.

**Quick mockups of how this interaction could take place. An array of sensors is spread across the surface and the amount of area that is lit/unlit will trigger an output.**





**An excerpt of my sketchbook, showing brainstorming, inspirations and initial sketches.**























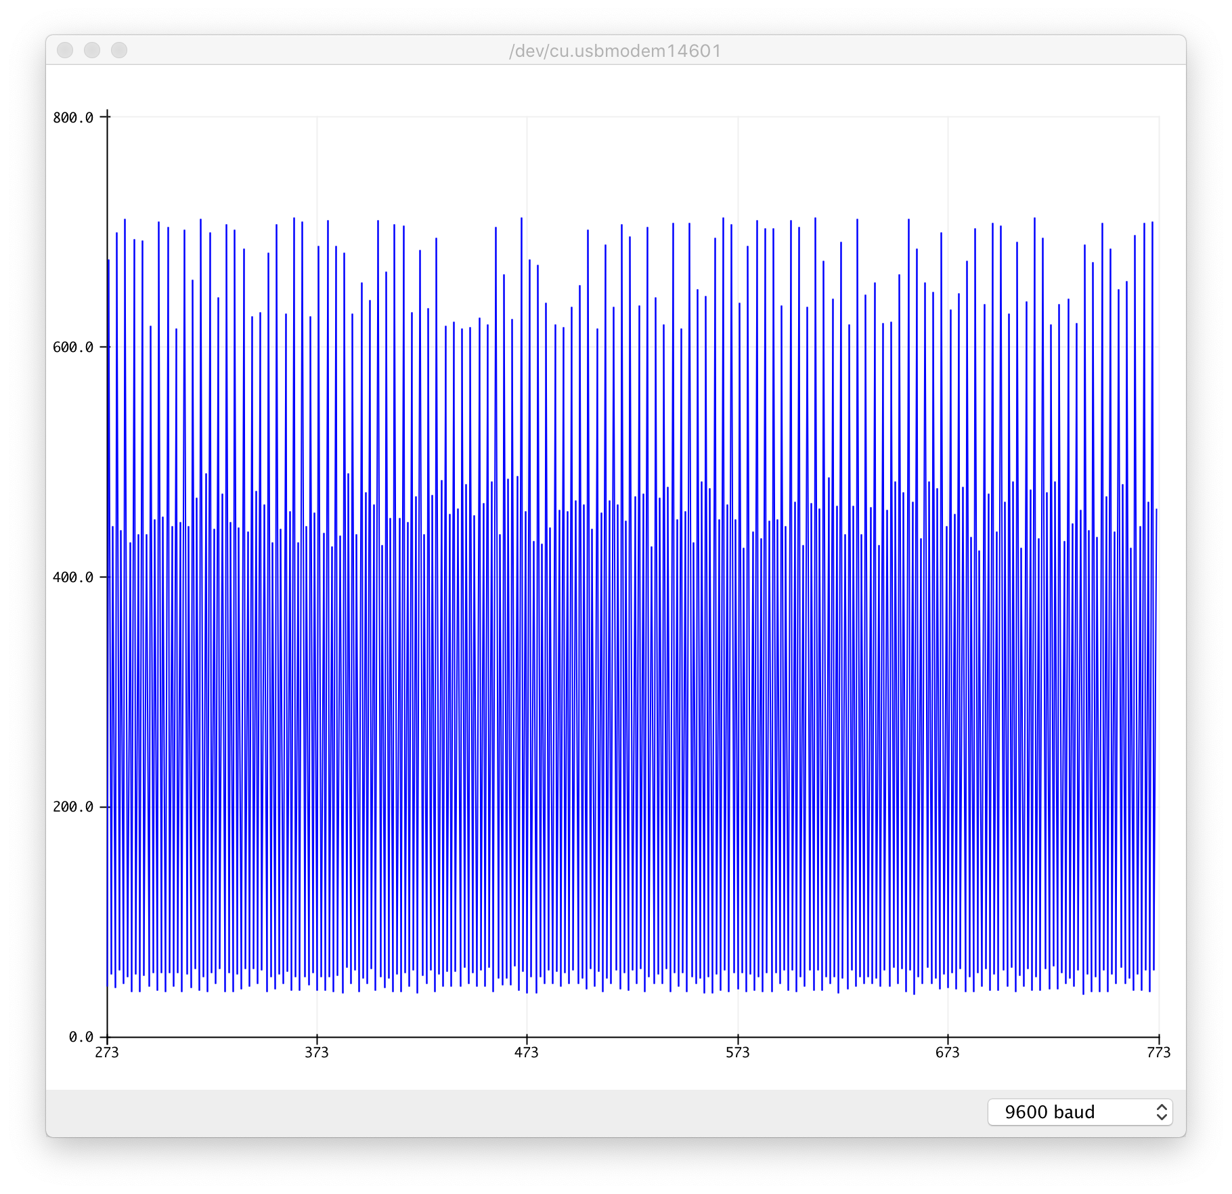
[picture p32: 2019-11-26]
journal/log-04/screenshot-0.png

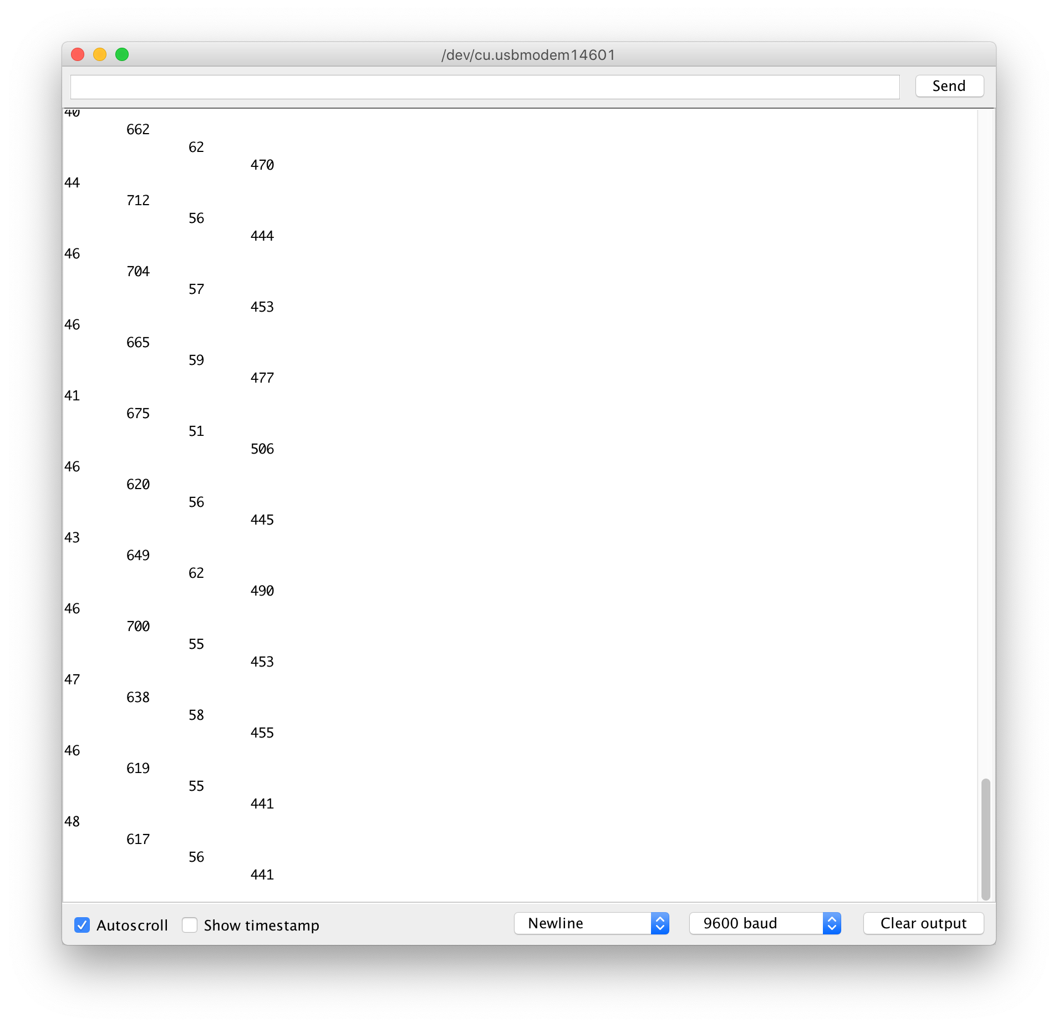
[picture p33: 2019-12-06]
journal/log-04/Bildschirmfoto 2019-11-26 um 15.17.12.png

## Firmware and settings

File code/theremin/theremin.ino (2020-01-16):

/*******************************
  ╔╦╗╦ ╦╔═╗╦═╗╔═╗╔╦╗╦╔╗╔
   ║ ╠═╣║╣ ╠╦╝║╣ ║║║║║║║ 
   ╩ ╩ ╩╚═╝╩╚═╚═╝╩ ╩╩╝╚╝
  Experimental instrument that uses light as
  an interface to output tones & melodies.
  It can be played by a single player or as a
  dialog between two.
*******************************/

#include "ISL29125_SoftWire.h"
#include "SFE_ISL29125.h"
#include "header.h"

void setup() {
  Serial.begin(9600);
  initialize();
  calibrate();
}

void loop() {
  light();
  fetchPhoto();
  fetchColor();
  music(speaker1, colorAvg);
}

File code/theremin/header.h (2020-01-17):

#pragma once

ISL29125_SOFT RGB_sensor_1;
ISL29125_SOFT RGB_sensor_2;
ISL29125_SOFT RGB_sensor_3;
ISL29125_SOFT RGB_sensor_4;

// speakers
int speaker1 = 3;
int speaker2 = 2;

// photoresistors
int photo1pin = A0;
int photo2pin = A1;
int photo3pin = A2;
int photo4pin = A3;
unsigned int photo1in, photo2in, photo3in, photo4in;

// color sensors
unsigned int red1, red2, red3, red4, green1, green2, green3, green4, blue1, blue2, blue3, blue4;
unsigned int redAvg, greenAvg, blueAvg;

// LEDs
int ledA1 = 6;
int ledA2 = 8;
int ledA3 = 11;
int ledA4 = 12;
int ledB1 = 7;
int ledB2 = 5;
int ledB3 = 13;
int ledB4 = 4;

// callibration
unsigned int photoValue, photoAvg, photoMax, colorValue, colorAvg, colorMax;
int colorMin, photoMin = 1023;

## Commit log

2019-12-13 added schematic
    [schematic.fzz]
2019-12-13 updated schematic
    [schematic.fzz]
2020-01-12 added schematic to pres
    [schematic.fzz]
